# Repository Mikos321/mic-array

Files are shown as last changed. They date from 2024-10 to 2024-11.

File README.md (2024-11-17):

# Spidermic
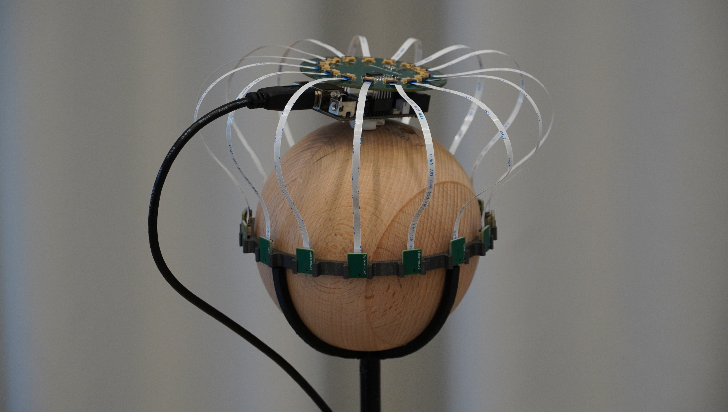
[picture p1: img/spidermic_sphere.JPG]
Spidermic
 
Spidermic is an low cost circular microphone array. For use in audio measurement applications such as [ambisonics](https://github.com/AppliedAcousticsChalmers/ambisonics-for-insta360-pro).
## Features
* Low cost spherical microphone array with up to 15 omnidirection microphones.
* Plug and play compatible with [Minidsp MCHstreamer](https://www.minidsp.com/products/usb-audio-interface/mchstreamer-lite).
* 15 PDM Infineon M73D122V01 Microphones.
* No programming required!
## Repository Organization
* [kicad/](kicad/) - KiCad schematic, layout and fabrication files for both the main PCB and microhpones
* [mounts/](mounts/) - STL Files for the ring mount.
## Documentation
The main board has 15 flatflex connectors, with a 24 degree angle between them, which allows for the microphones to be mounted equidistant to each other on the hemisphere of an wooden sphere with a radius of 60mm.
### Minidsp MCH-Streamer
The main board of the mic array is mounted on top of a MiniDSP MCH-Streamer connected to J2. 
Since the Infineon microphones work with 1.8v logic and the MCH-steamer only outputs 3.3v, I used Ti-SN74LVC8T245
level shifting from 3.3V to 1.8V of the data and clock signals to and from the MCH-streamer.
### Hand solder
While it should be possible to hand solder the current version of the main board, it might be tricky since components are somewhat tightly placed around the pinheader. This should get fixed in future versions.
I cannot recommend handsoldering the microphone boards since the microphones are very particular with paste application and temperature.
JLCpcba PCBA worked with well for the microphones.
### Mounting hardware
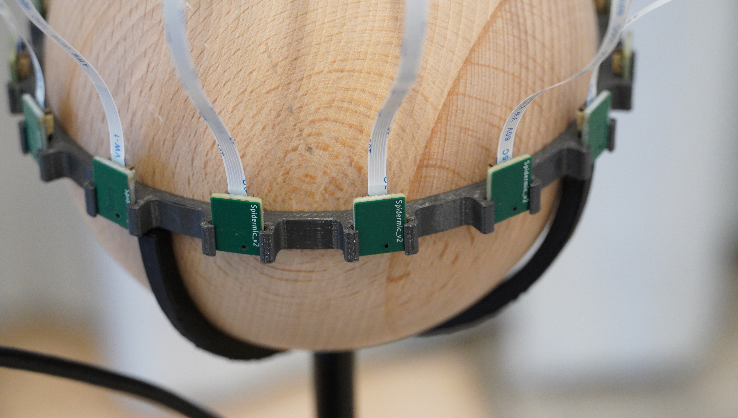
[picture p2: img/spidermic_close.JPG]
Microphones
The ring mount should be printed in PETG,fit around the sphere and the microphones are also friction fit in the "claws". 
Squeezing the ring to spread the claws makes it easier to mount the microphones as the tolerances are tight.

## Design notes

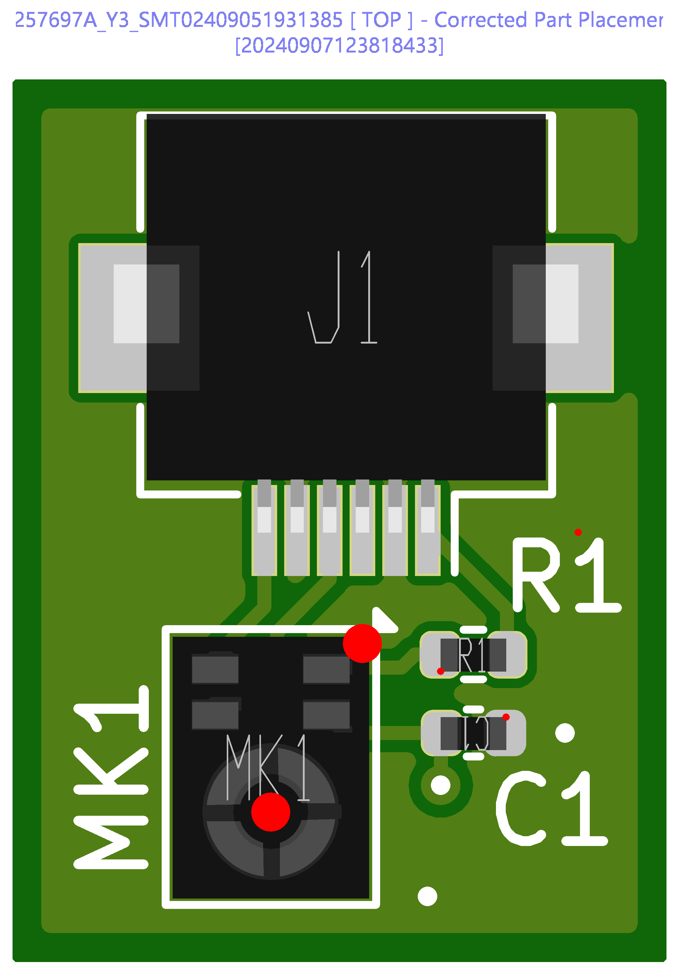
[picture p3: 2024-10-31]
kicad/spider-array-main-v3/18209207943168-Produce_DanZhi.SMT_Snapshot.Top.8257697A_Y3.SMT02409051931385.png

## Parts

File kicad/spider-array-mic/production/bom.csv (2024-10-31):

Designator | Footprint | Quantity | Value | LCSC Part #
C1 | 0603 | 1 | 100n
J1 | Hirose_FH12-6S-0.5SH_1x06-1MP_P0.50mm_Horizontal | 1 | Conn_01x06
MK1 | Infineon_PG-LLGA-5-1 | 1 | IM73D122
R1 | 0603 | 1 | 100

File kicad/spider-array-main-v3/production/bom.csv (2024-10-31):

Designator | Footprint | Quantity | Value | LCSC Part #
C1, C2, C3, C4, C5, C6 | 402 | 6 | 1uF
J1, J2 | PinSocket_2x06_P2.00mm_Vertical | 2 | MCH-J3
J10, J11, J12, J13, J14, J15, J16, J17, J3, J4, J5, J6, J7, J8, J9 | Hirose_FH12-6S-0.5SH_1x06-1MP_P0.50mm_Horizontal | 15 | Conn_01x06_Socket
R1 | 402 | 1 | 33
R4, R5 | 402 | 2 | 2K
U1 | SOT-23-5 | 1 | LP5907MFX-1.8
U2 | SOP65P640X120-24N | 1 | SN74LVC8T245PW
U3 | SOT95P280X145-6N | 1 | SN74AVCH1T45DBVR

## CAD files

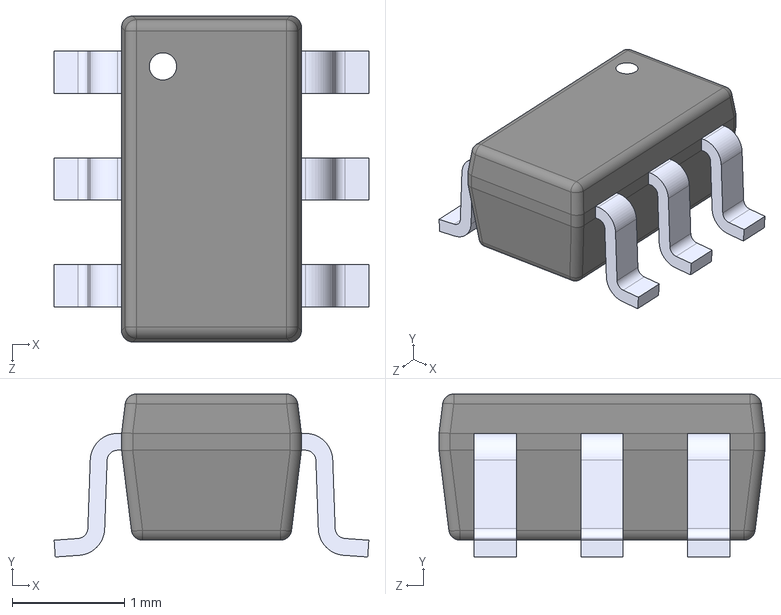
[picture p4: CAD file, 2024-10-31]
kicad/spider-array-main-v3/projlib/SN74AVCH1T45DBVR/SN74AVCH1T45DBVR.step
2.80 x 1.45 x 2.90 mm

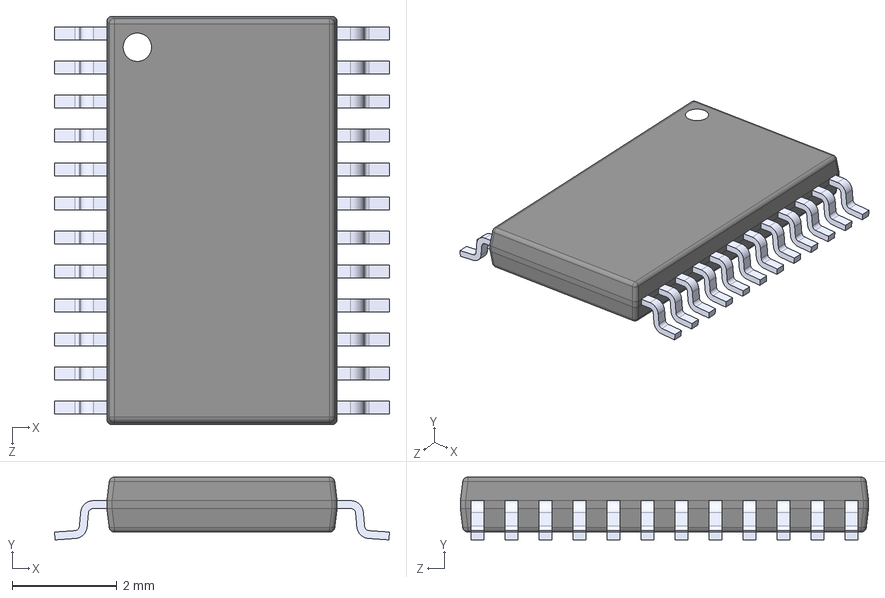
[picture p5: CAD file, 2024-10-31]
kicad/spider-array-main-v3/projlib/SN74LVC8T245PW/SN74LVC8T245PW.step
6.40 x 1.20 x 7.80 mm

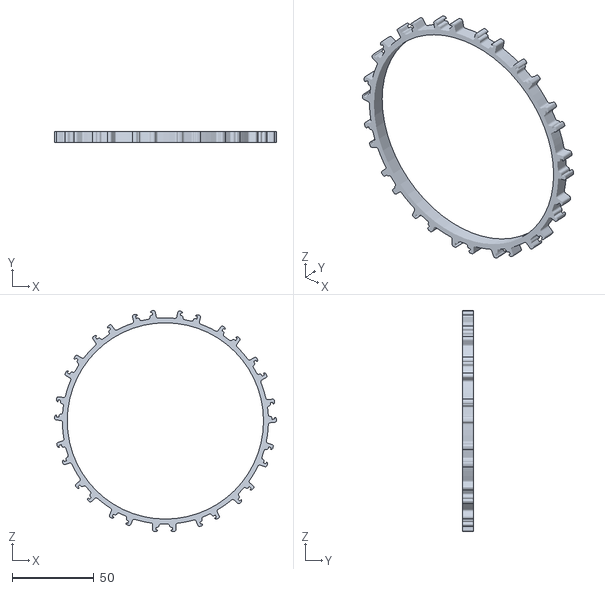
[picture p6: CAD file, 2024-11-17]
mounts/MM-D120_v4.stl
135.7 x 7.00 x 135.1

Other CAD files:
mounts/MM-D120.ipt

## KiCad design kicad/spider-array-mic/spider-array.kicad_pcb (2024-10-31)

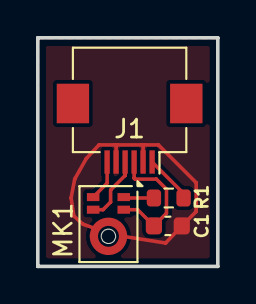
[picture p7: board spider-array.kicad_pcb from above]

Board: 2 copper layers, 10.0 x 12.7 mm, 4 parts (0 on the bottom side), 6 nets.

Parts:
C1: 100n; C_0603_1608Metric
J1: Conn_01x06; Hirose_FH12-6S-0.5SH_1x06-1MP_P0.50mm_Horizontal
MK1: IM73D122; Infineon_PG-LLGA-5-1
R1: 100; R_0603_1608Metric

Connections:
GND: C1.1, J1.2, J1.5, MK1.5 (GND)
unnamed: MK1.1 (DATA), R1.1
PDM_CLK: J1.6, MK1.3 (CLOCK)
PDM_DATA: J1.1, R1.2
SLCT: J1.4, MK1.4 (SELECT)
VDD: C1.2, J1.3, MK1.2 (VDD)

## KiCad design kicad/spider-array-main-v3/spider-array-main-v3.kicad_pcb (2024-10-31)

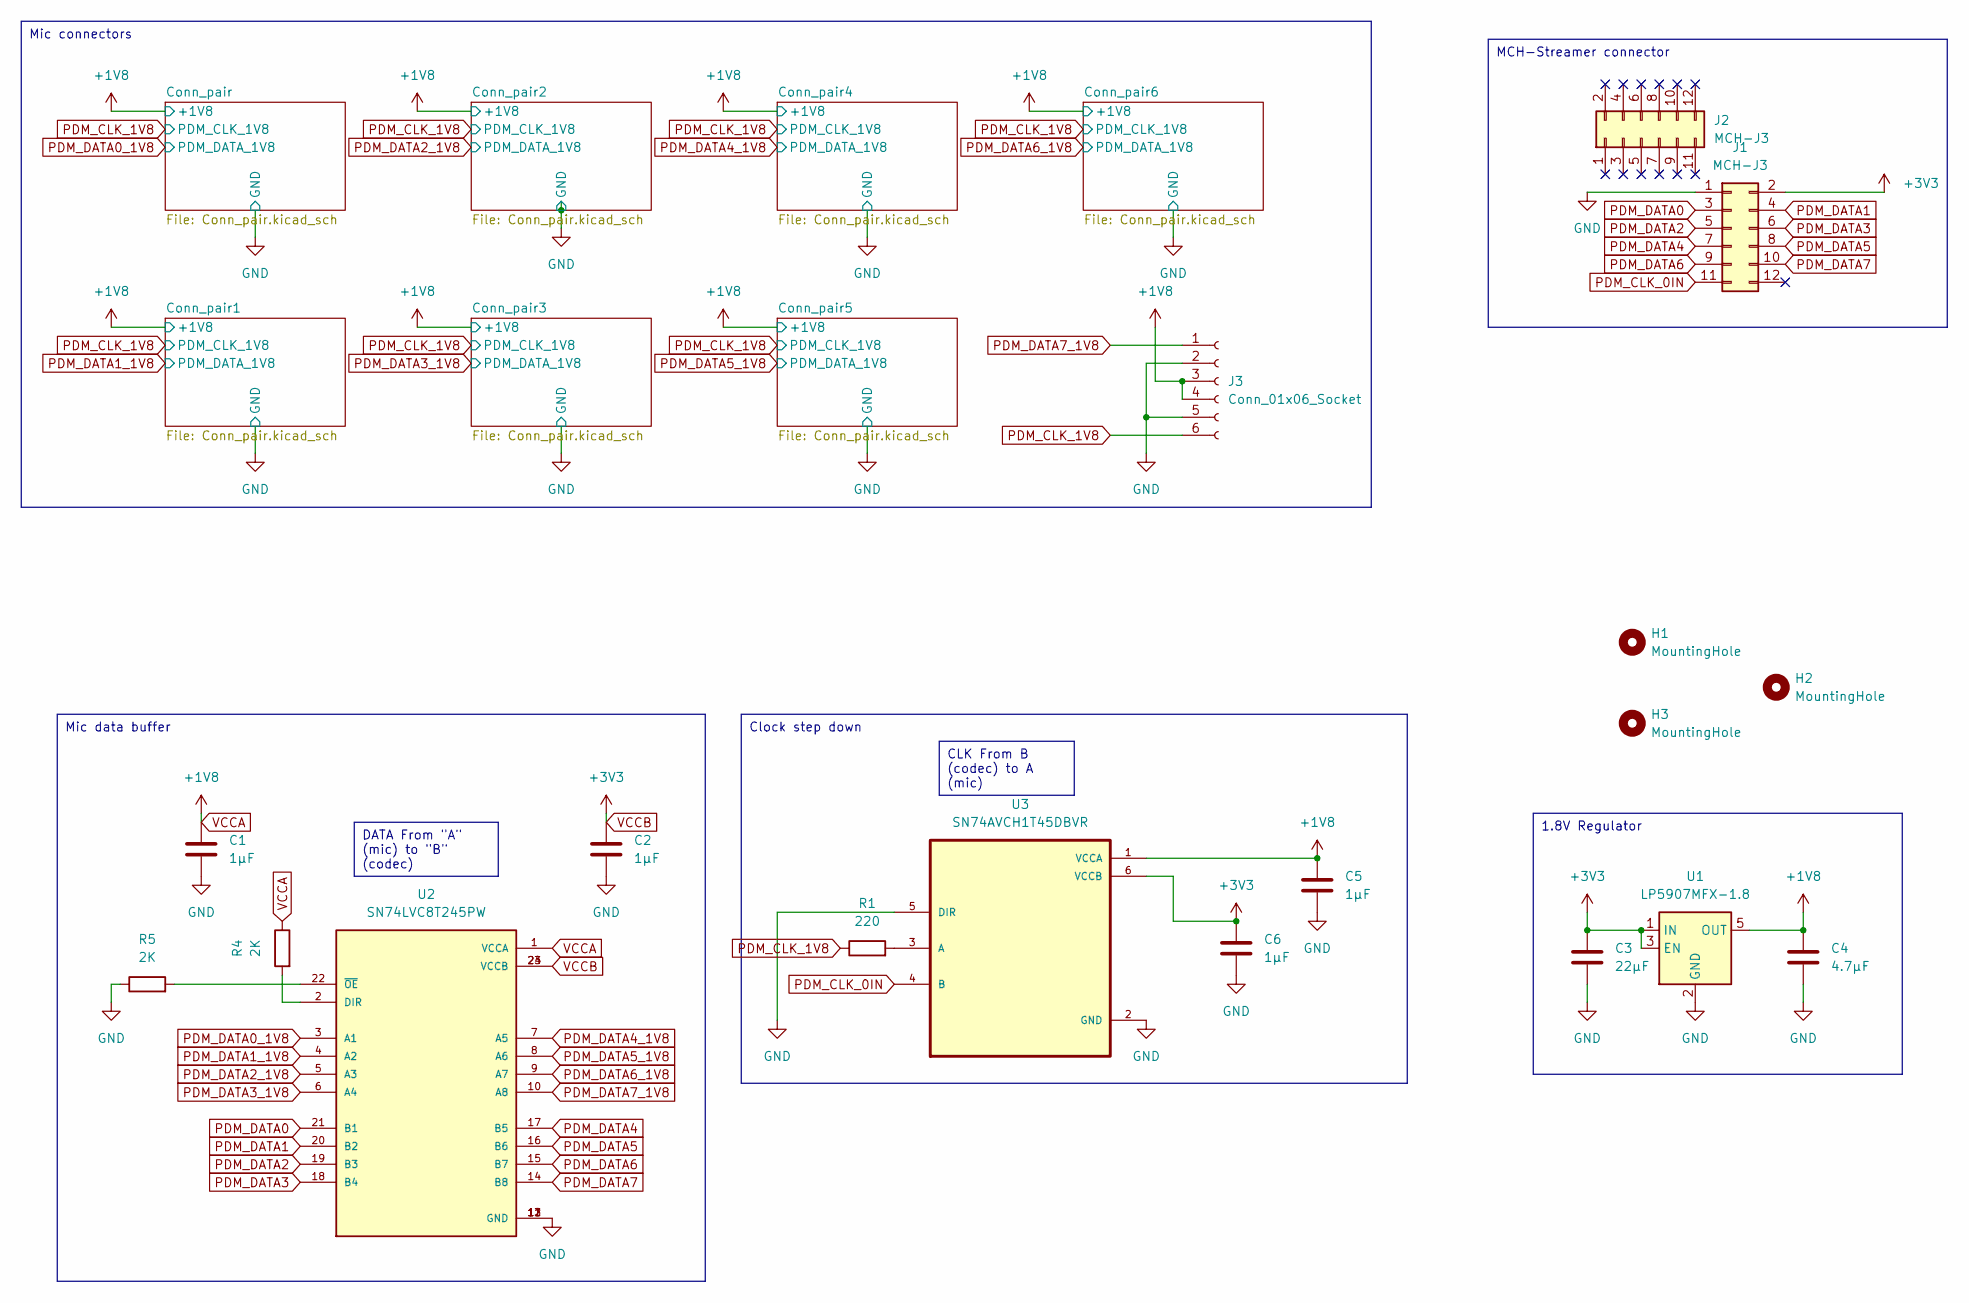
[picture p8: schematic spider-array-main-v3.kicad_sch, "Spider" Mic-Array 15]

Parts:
C1, C2, C5, C6: 1µF; C_0402_1005Metric
C3: 22µF; C_0805_2012Metric
C4: 4.7µF; C_0603_1608Metric
H1, H2, H3: MountingHole; MountingHole_3.2mm_M3
J1, J2: MCH-J3; PinSocket_2x06_P2.00mm_Vertical
J3: Conn_01x06_Socket; Hirose_FH12-6S-0.5SH_1x06-1MP_P0.50mm_Horizontal
R1: 220; R_0402_1005Metric
R4, R5: 2K; R_0402_1005Metric
U1: LP5907MFX-1.8; SOT-23-5
U2: SN74LVC8T245PW; SOP65P640X120-24N; PARTREV B
U3: SN74AVCH1T45DBVR; SOT95P280X145-6N

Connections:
GND: C1.2, C2.2, C3.2, C4.2, C5.2, C6.2, J1.1, J3.2, J3.5, R5.1, U1.2 (GND), U2.11 (GND), U2.12 (GND), U2.13 (GND), U3.2 (GND), U3.5 (DIR); also elsewhere on the board
unnamed: R4.2, U2.2 (DIR)
unnamed: R5.2, U2.22 (~OE)
unnamed: R1.2, U3.3 (A)
PDM_CLK_0IN: J1.11, U3.4 (B)
PDM_CLK_1V8: J3.6, R1.1; also elsewhere on the board
PDM_DATA0: J1.3, U2.21 (B1)
PDM_DATA0_1V8: U2.3 (A1); also elsewhere on the board
PDM_DATA1: J1.4, U2.20 (B2)
PDM_DATA1_1V8: U2.4 (A2); also elsewhere on the board
PDM_DATA2: J1.5, U2.19 (B3)
PDM_DATA2_1V8: U2.5 (A3); also elsewhere on the board
PDM_DATA3: J1.6, U2.18 (B4)
PDM_DATA3_1V8: U2.6 (A4); also elsewhere on the board
PDM_DATA4: J1.7, U2.17 (B5)
PDM_DATA4_1V8: U2.7 (A5); also elsewhere on the board
PDM_DATA5: J1.8, U2.16 (B6)
PDM_DATA5_1V8: U2.8 (A6); also elsewhere on the board
PDM_DATA6: J1.9, U2.15 (B7)
PDM_DATA6_1V8: U2.9 (A7); also elsewhere on the board
PDM_DATA7: J1.10, U2.14 (B8)
PDM_DATA7_1V8: J3.1, U2.10 (A8)
VCCA: C1.1, C4.1, C5.1, J3.3, J3.4, R4.1, U1.5 (OUT), U2.1 (VCCA), U3.1 (VCCA); also elsewhere on the board
VCCB: C2.1, C3.1, C6.1, J1.2, U1.1 (IN), U1.3 (EN), U2.23 (VCCB), U2.24 (VCCB), U3.6 (VCCB)

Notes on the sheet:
Mic data buffer
MCH-Streamer connector
Mic connectors
Clock step down
DATA From "A" (mic) to "B" (codec)
CLK From B (codec) to A (mic)
1.8V Regulator

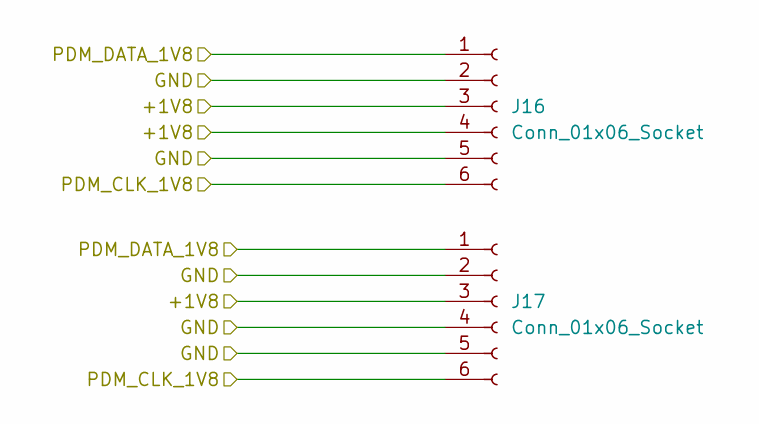
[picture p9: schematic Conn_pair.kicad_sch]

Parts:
J16, J17: Conn_01x06_Socket; Hirose_FH12-6S-0.5SH_1x06-1MP_P0.50mm_Horizontal

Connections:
GND: J16.2, J16.5, J17.2, J17.4, J17.5; also elsewhere on the board
PDM_CLK_1V8: J16.6, J17.6; also elsewhere on the board
PDM_DATA6_1V8: J16.1, J17.1; also elsewhere on the board
VCCA: J16.3, J16.4, J17.3; also elsewhere on the board

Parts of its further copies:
J4, J5, J6, J7, J8, J9, J10, J11, J12, J13, J14, J15: Conn_01x06_Socket; Hirose_FH12-6S-0.5SH_1x06-1MP_P0.50mm_Horizontal

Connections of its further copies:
GND: J4.2, J4.5, J5.2, J5.4, J5.5, J6.2, J6.5, J7.2, J7.4, J7.5, J8.2, J8.5, J9.2, J9.4, J9.5, J10.2, J10.5, J11.2, J11.4, J11.5, J12.2, J12.5, J13.2, J13.4, J13.5, J14.2, J14.5, J15.2, J15.4, J15.5; also elsewhere on the board
PDM_CLK_1V8: J4.6, J5.6, J6.6, J7.6, J8.6, J9.6, J10.6, J11.6, J12.6, J13.6, J14.6, J15.6; also elsewhere on the board
PDM_DATA0_1V8: J4.1, J5.1; also elsewhere on the board
PDM_DATA1_1V8: J6.1, J7.1; also elsewhere on the board
PDM_DATA2_1V8: J8.1, J9.1; also elsewhere on the board
PDM_DATA3_1V8: J10.1, J11.1; also elsewhere on the board
PDM_DATA4_1V8: J12.1, J13.1; also elsewhere on the board
PDM_DATA5_1V8: J14.1, J15.1; also elsewhere on the board
VCCA: J4.3, J4.4, J5.3, J6.3, J6.4, J7.3, J8.3, J8.4, J9.3, J10.3, J10.4, J11.3, J12.3, J12.4, J13.3, J14.3, J14.4, J15.3; also elsewhere on the board

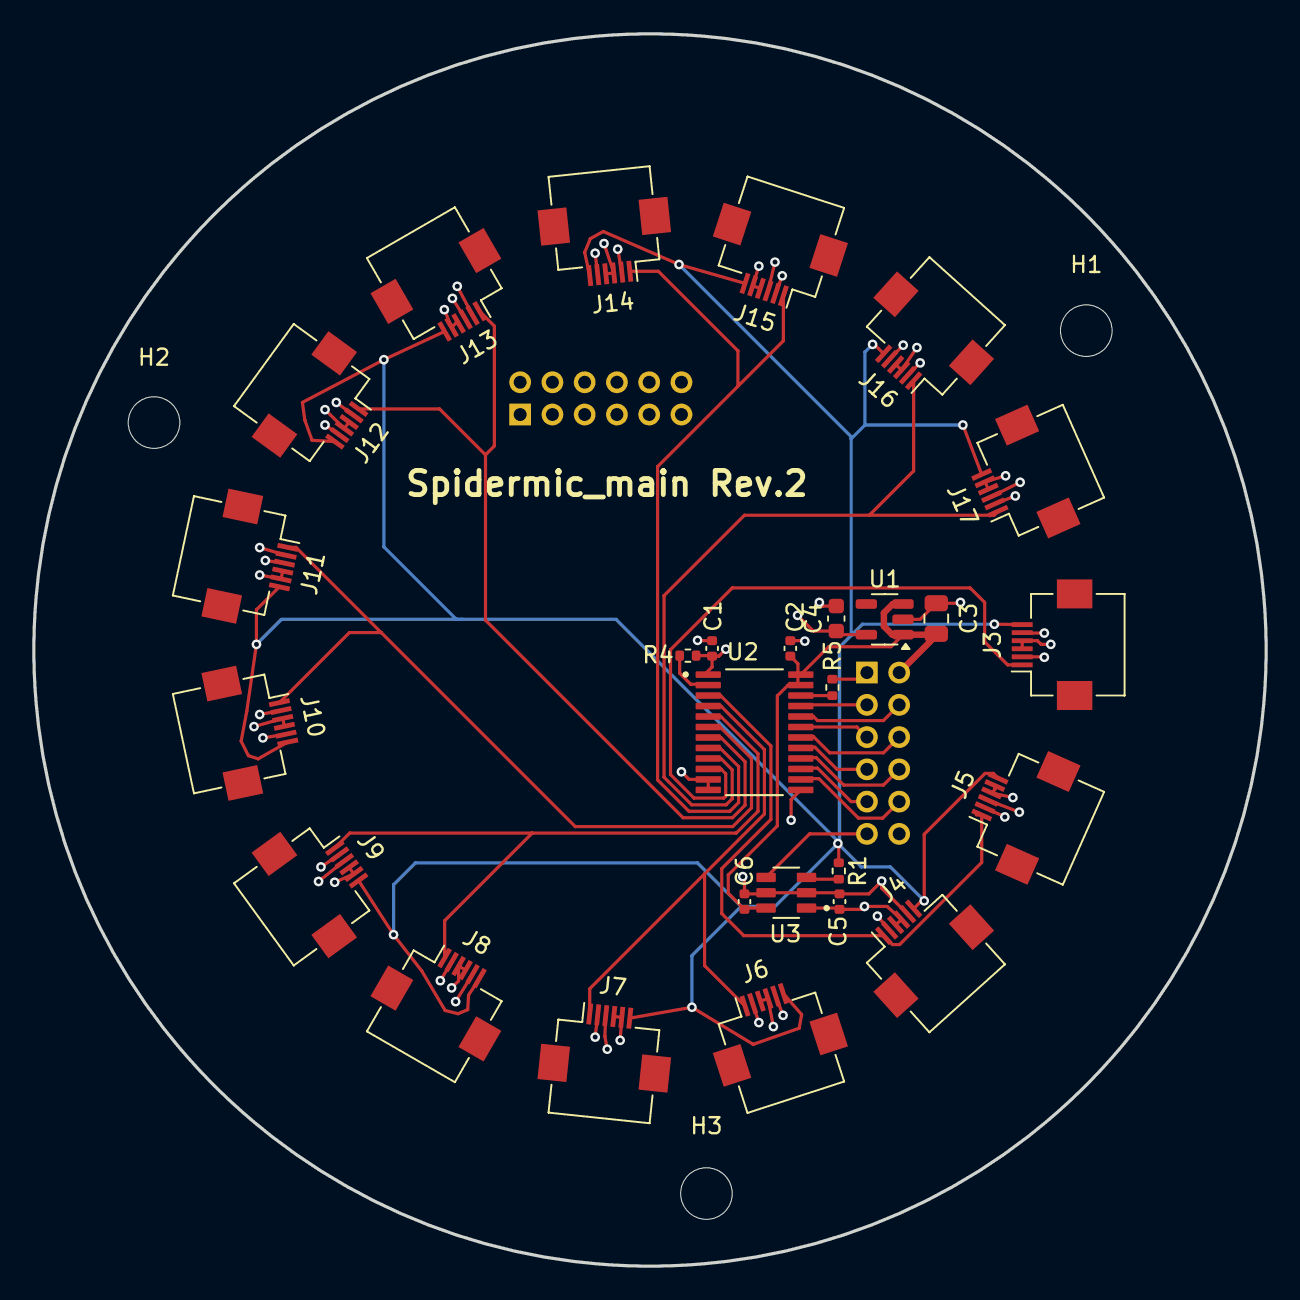
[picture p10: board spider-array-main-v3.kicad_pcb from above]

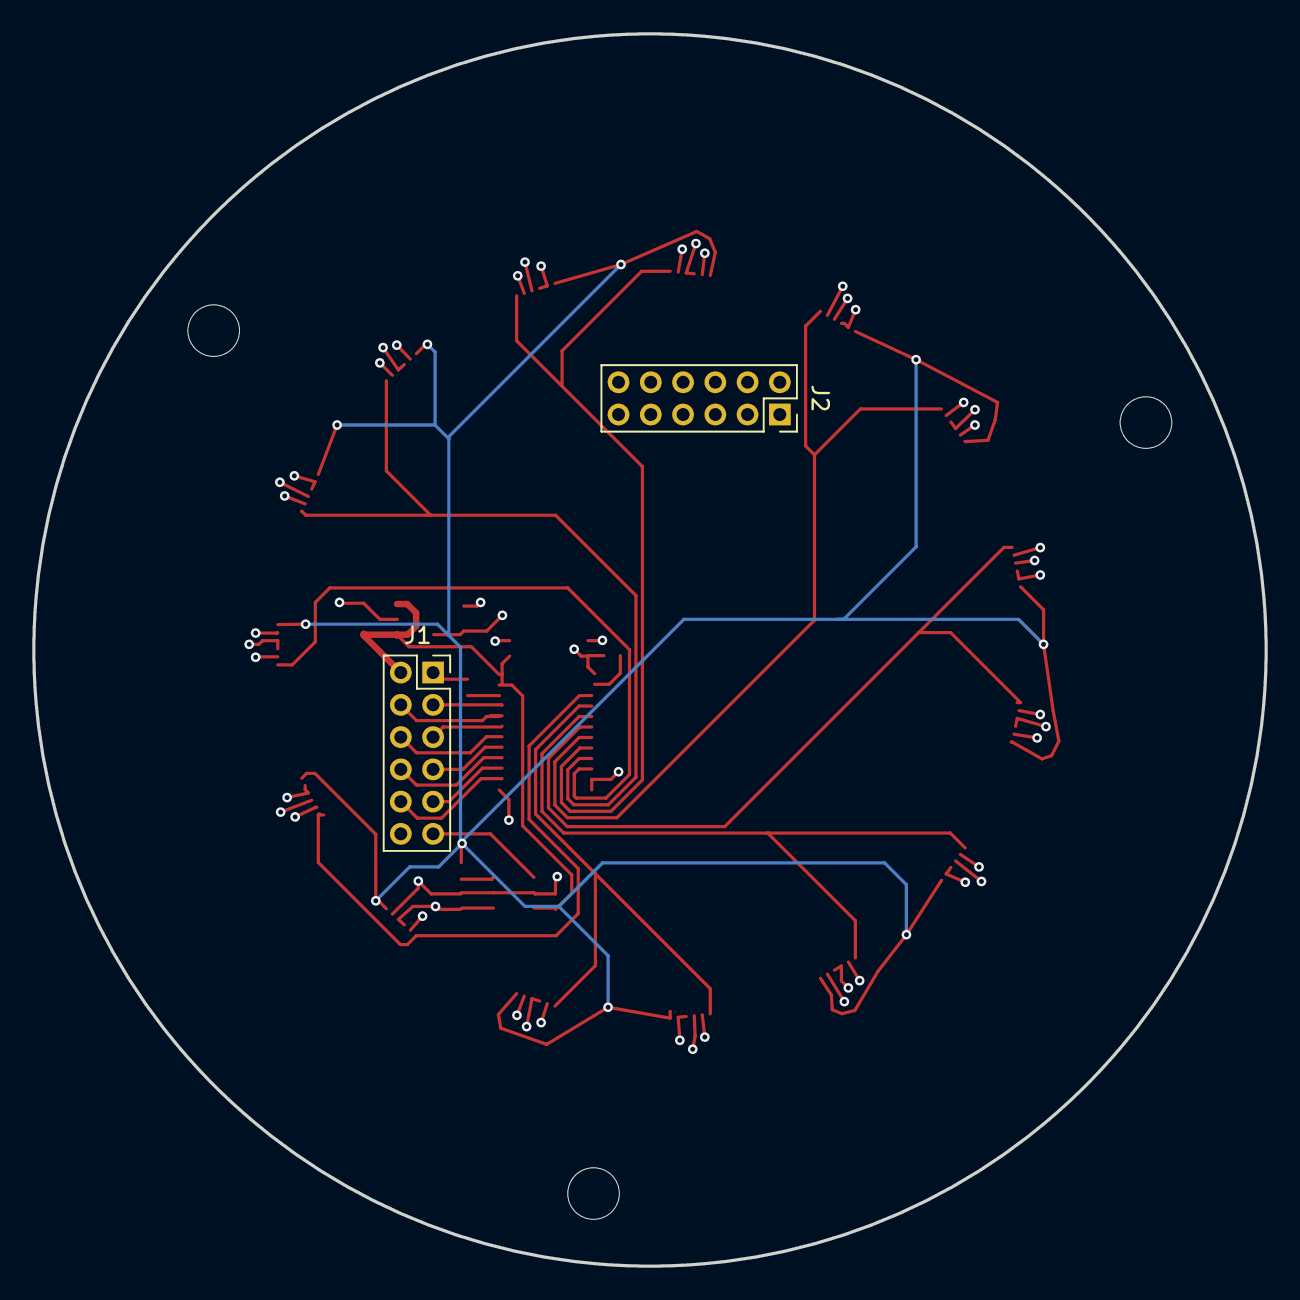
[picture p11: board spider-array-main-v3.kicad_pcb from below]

Board: 4 copper layers, 76.4 x 76.4 mm, 32 parts (2 on the bottom side), 24 nets.

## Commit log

2024-10-31 initial move to github of project files
    [Conn_pair.kicad_sch, MM-D120.0002.ipt, MM-D120.ipt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]
2024-11-17 Created Readme and added pictures, mount stl files...
    [Conn_pair.kicad_sch, MM-D120.0002.ipt, MM-D120.stl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]
